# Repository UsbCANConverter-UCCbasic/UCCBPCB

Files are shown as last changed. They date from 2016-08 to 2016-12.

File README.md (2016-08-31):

# PCB for UsbCANConverterBasic
This is PCB for UsbCANConverter basic, designed in free software KiCad.
#License
UsbCANConverterBasic is free software: you can redistribute it and/or modify it under the terms of the GNU Lesser General Public License as published by the Free Software Foundation, either version 3 of the License, or (at your option) any later version. Project is distributed in the hope that it will be useful, but WITHOUT ANY WARRANTY; without even the implied warranty of MERCHANTABILITY or FITNESS FOR A PARTICULAR PURPOSE. See the GNU Lesser General Public License for more details.

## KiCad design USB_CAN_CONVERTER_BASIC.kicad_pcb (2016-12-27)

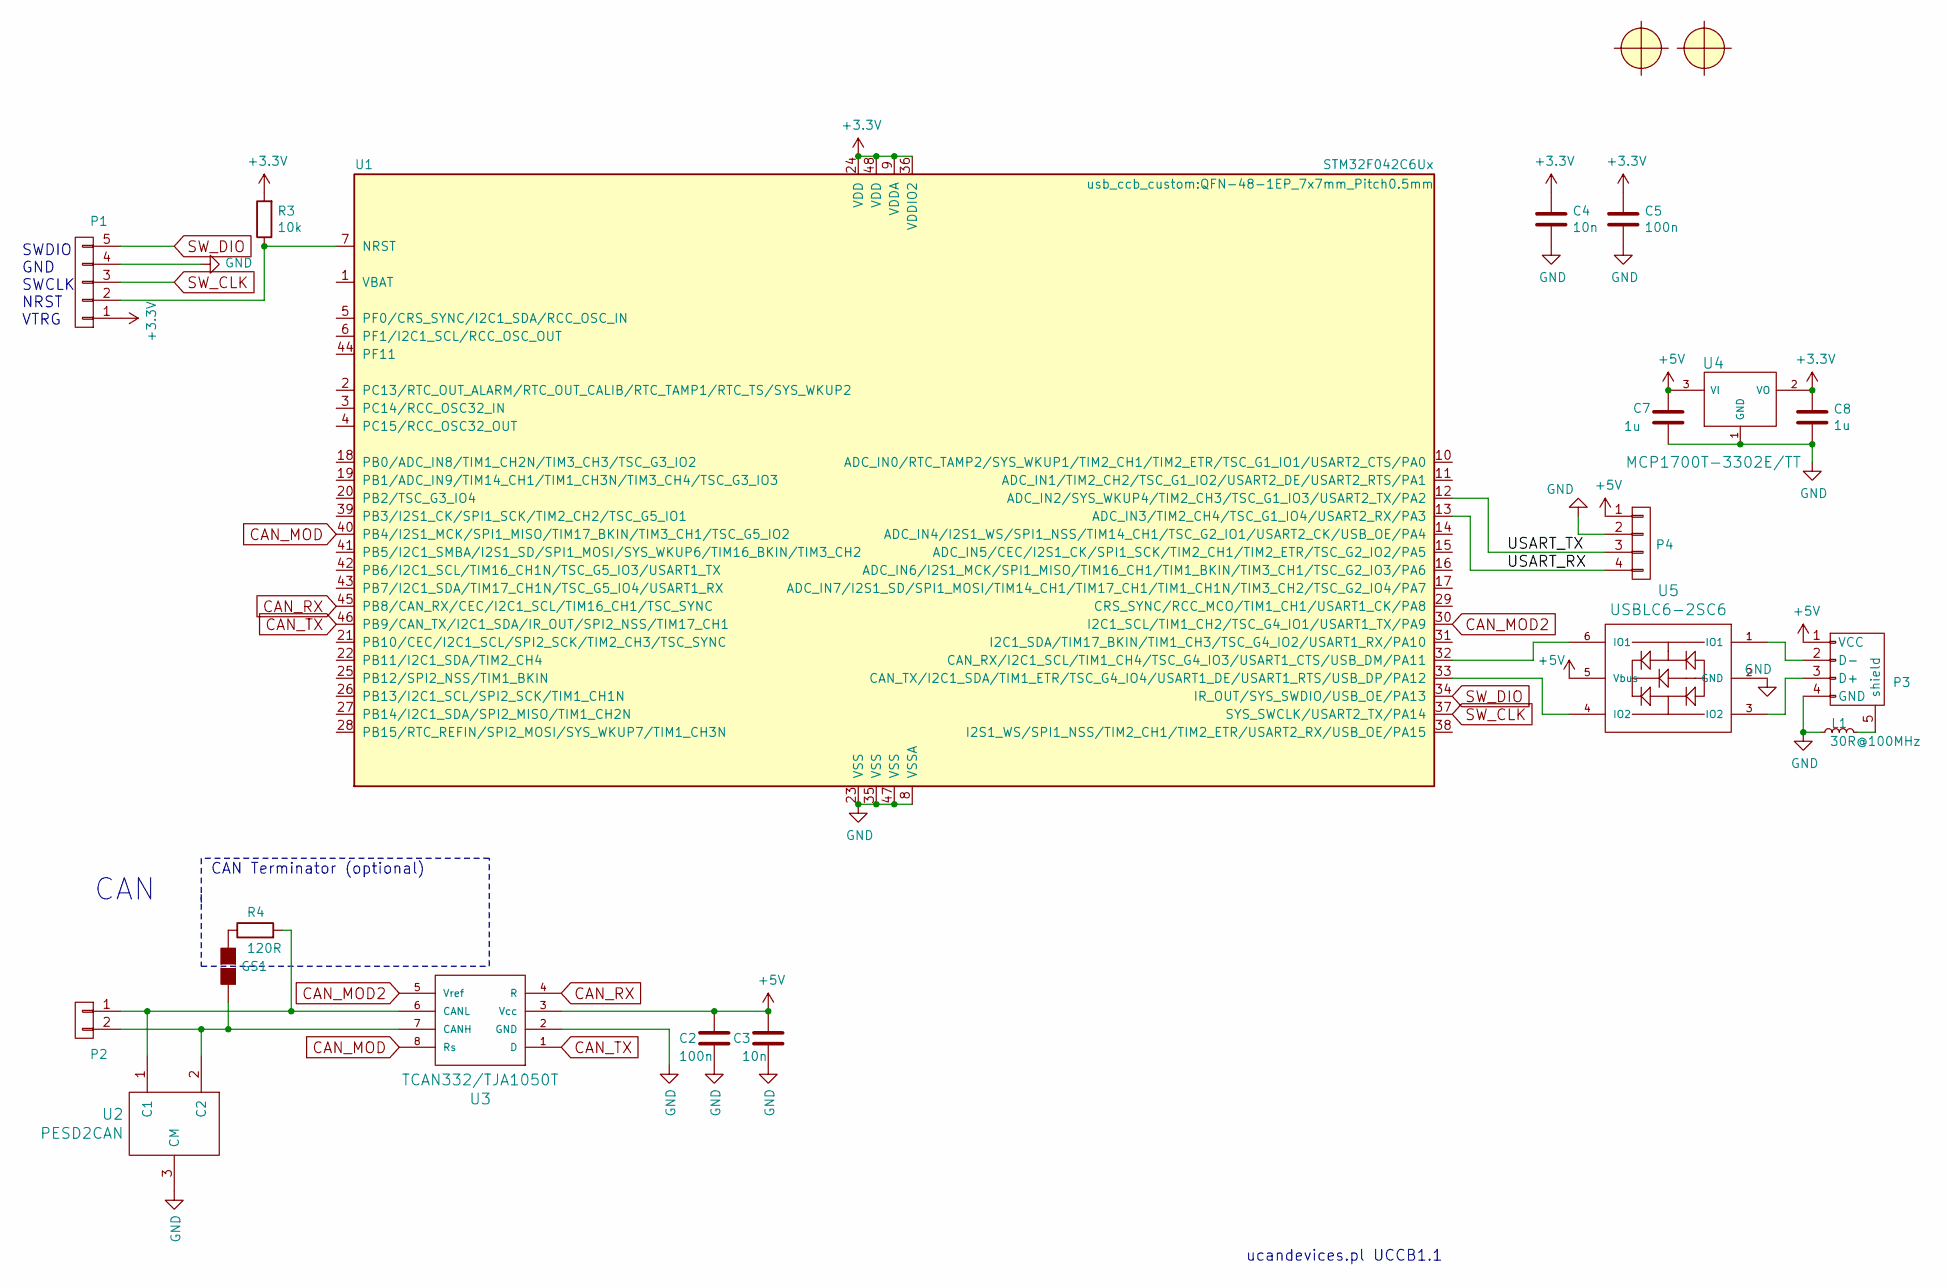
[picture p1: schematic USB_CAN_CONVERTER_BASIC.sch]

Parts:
C2, C5: 100n; C_0805; MFG Part Num C0805C104K3RAC
C3, C4: 10n; C_0805; MFG Part Num 08053C103KAT2A
C7, C8: 1u; C_0805; MFG Part Num 08053G105ZAT2A
F1: fiducial; Fiducial_1mm_Dia_2.54mm_Outer_CopperTop
F2: fiducial; Fiducial_1mm_Dia_2.54mm_Outer_CopperBottom
GS1: GS2
L1: 30R@100MHz; C_0805; MFG Part Num DL0805-0.82
P1: CONN_01X05; swd_smd_conn5
P2: CONN_01X02; AK300-2; MFG Part Num DG126-5.0-2P14
P3: USB_A; USB_A_DS1097R; MFG Part Num DS1097-BN0
P4: CONN_01X04; Pin_Header_Angled_1x04m
R3: 10k; R_0805; MFG Part Num CRCW080510K0FKEA
R4: 120R; R_0603; MFG Part Num SMD0805-120R
U1: STM32F042C6Ux; QFN-48-1EP_7x7mm_Pitch0.5mm; MFG Part Num STM32F042C6U6
U2: PESD2CAN; SOT-23; MFG Part Num PESD2CAN.215
U3: TCAN332/TJA1050T; SO; MFG Part Num TJA1050T/CM
U4: MCP1700T-3302E/TT; SOT-23; MFG Part Num MCP1700T-3302E/TT
U5: USBLC6-2SC6; SOT-23-6; MFG Part Num USBLC6-2SC6

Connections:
+3V3: C4.1, C5.1, C8.1, P1.1, R3.2, U1.9 (VDDA), U1.24 (VDD), U1.36 (VDDIO2), U1.48 (VDD), U4.2 (VO)
+5V: C2.1, C3.1, C7.1, P3.1 (VCC), P4.1, U3.3 (Vcc), U4.3 (VI), U5.5 (Vbus)
/USART_RX: P4.4, U1.13 (ADC_IN3/TIM2_CH4/TSC_G1_IO4/USART2_RX/P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)
/USART_TX: P4.3, U1.12 (ADC_IN2/SYS_WKUP4/TIM2_CH3/TSC_G1_IO3/U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)
CAN_MOD: U1.40 (PB4/I2S1_MCK/SPI1_MISO/TIM17_BKIN/TIM3_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), U3.8 (Rs)
CAN_MOD2: U1.30 (I2C1_SCL/TIM1_CH2/TSC_G4_IO1/USART1_TX/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), U3.5 (Vref)
CAN_RX: U1.45 (PB8/CAN_RX/CEC/I2C1_SCL/TIM16_CH1/TSC_S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), U3.4 (R)
CAN_TX: U1.46 (PB9/CAN_TX/I2C1_SDA/IR_OUT/SPI2_NSS/TIM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), U3.1 (D)
GND: C2.2, C3.2, C4.2, C5.2, C7.2, C8.2, L1.1, P1.4, P3.4 (GND), P4.2, U1.8 (VSSA), U1.23 (VSS), U1.35 (VSS), U1.47 (VSS), U1.49, U2.3 (CM), U3.2 (GND), U4.1 (GND), U5.2 (GND)
unnamed: GS1.1 (G1), R4.1
unnamed: GS1.2 (G2), P2.2, U2.2 (C2), U3.7 (CANH)
unnamed: L1.2, P3.5 (shield)
unnamed: P1.2, R3.1, U1.7 (NRST)
unnamed: P2.1, R4.2, U2.1 (C1), U3.6 (CANL)
unnamed: P3.2 (D-), U5.1 (IO1)
unnamed: P3.3 (D+), U5.3 (IO2)
unnamed: U1.32 (CAN_RX/I2C1_SCL/TIM1_CH4/TSC_G4_IO3/USA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), U5.6 (IO1)
unnamed: U1.33 (CAN_TX/I2C1_SDA/TIM1_ETR/TSC_G4_IO4/USA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), U5.4 (IO2)
SW_CLK: P1.3, U1.37 (SYS_SWCLK/USART2_TX/PA14)
SW_DIO: P1.5, U1.34 (IR_OUT/SYS_SWDIO/USB_OE/PA13)

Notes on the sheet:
SWDIO GND SWCLK NRST VTRG
CAN
CAN Terminator (optional)
ucandevices.pl UCCB1.1

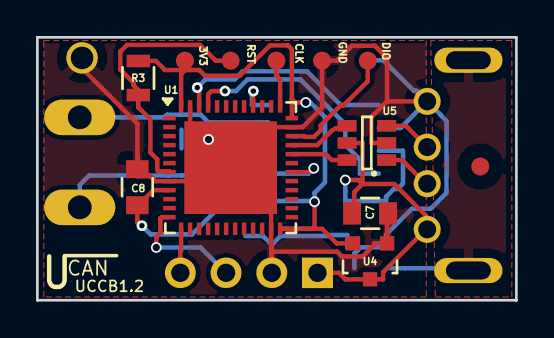
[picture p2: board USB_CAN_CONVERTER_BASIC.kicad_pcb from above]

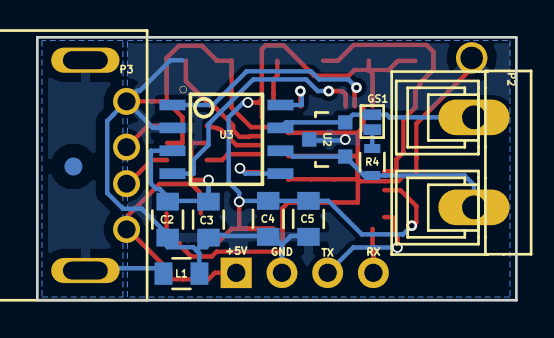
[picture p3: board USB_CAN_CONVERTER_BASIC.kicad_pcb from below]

Board: 2 copper layers, 26.6 x 14.6 mm, 21 parts (11 on the bottom side), 20 nets.

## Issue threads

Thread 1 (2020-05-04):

Modify board to add placeholder for smd dip switch and termination resistor

ksuszka, 2020-05-04:
Just an idea - there is a place for termination resistor already on board, however it would be nice to have ability to enable/disable it without soldering. It could be achieved by adding resistor with binary dip switch in series. It could be optional, as it shouldn't interfere with the rest of the board.

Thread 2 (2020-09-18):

Schema says TCAN332 or TJA1050, but only TJA1050 works

daniellandau, 2020-09-18:
TCAN332 requires 3.3V Vcc and refuses to send/receive anything when supplied with 5V as current UCCB design does.

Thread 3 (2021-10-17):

Suggestion: Configuration Jumpers

milesfrain, 2021-10-17:
For future HW revisions, it would be great to have easy configuration with 0.1" pitch jumpers on the following:
- `GS1` for termination (and / or the switch footprint suggestion in #1)
- Breaking `CAN_TX` and `CAN_RX` so the board can be re-purposed as a simple transceiver breakout for testing CAN on other micros (e.g. without using the included STM32 and USB).

To keep manufacturing simple and not add to the BOM, just the through-hole footprints could be added for users to populate themselves if they wish. In the case of the `CAN_TX` and `CAN_RX` interruption, we can score the trace to break the existing connection.

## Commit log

2016-07-04 USB and CAN connector fix
    [USB_CAN_CONVERTER_BASIC.kicad_pcb, USB_CAN_CONVERTER_BASIC.sch]
2016-07-05 UART1 switch, logo creation, CAN footprint update, botom layer replacement.
    UART1 switch, logo creation, CAN footprint update, botom layer
    replacement.
    [USB_CAN_CONVERTER_BASIC.dsn, USB_CAN_CONVERTER_BASIC.kicad_pcb, USB_CAN_CONVERTER_BASIC.sch]
2016-07-09 SWD connector update, logo generation, board otline update.
    [USB_CAN_CONVERTER_BASIC.kicad_pcb, USB_CAN_CONVERTER_BASIC.sch]
2016-07-09 CAN Jumpers addition
    [USB_CAN_CONVERTER_BASIC.kicad_pcb, USB_CAN_CONVERTER_BASIC.sch]
2016-07-11 Outline size reduction
    [USB_CAN_CONVERTER_BASIC.dsn, USB_CAN_CONVERTER_BASIC.kicad_pcb, USB_CAN_CONVERTER_BASIC.sch]
2016-07-11 USART change
    [USB_CAN_CONVERTER_BASIC.dsn, USB_CAN_CONVERTER_BASIC.kicad_pcb, USB_CAN_CONVERTER_BASIC.sch]
2016-07-12 Board rooting done.
    [USB_CAN_CONVERTER_BASIC.dsn, USB_CAN_CONVERTER_BASIC.kicad_pcb, USB_CAN_CONVERTER_BASIC.sch]
2016-07-12 Thermal pad update
    [USB_CAN_CONVERTER_BASIC.dsn, USB_CAN_CONVERTER_BASIC.kicad_pcb]
2016-07-12 BOM addition
    [bom.xlsx]
2016-07-13 Rooting and CANmod replace.
    [USB_CAN_CONVERTER_BASIC.dsn, USB_CAN_CONVERTER_BASIC.kicad_pcb, USB_CAN_CONVERTER_BASIC.sch]
2016-07-13 Gerber and drill generation
    [USB_CAN_CONVERTER_BASIC-B.CrtYd.gbr, USB_CAN_CONVERTER_BASIC-B.Cu.gbl, USB_CAN_CONVERTER_BASIC-B.Cu.gbr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]
2016-07-13 BOM update
    BOM update
    [bom.xlsx]
2016-08-13 Panel pcb addition and stencils.
    [USB_CAN_CONVERTER_BASIC.sch, bom.xlsx]
2016-10-04 Schematic name update
    Schematic name update
    [USB_CAN_CONVERTER_BASIC.sch]
2016-12-08 Fiducial Add
    Fiducial Add
    [USB_CAN_CONVERTER_BASIC.kicad_pcb, USB_CAN_CONVERTER_BASIC.sch]
2016-12-08 components description update
    components description update
    [USB_CAN_CONVERTER_BASIC.kicad_pcb, USB_CAN_CONVERTER_BASIC.sch]
2016-12-09 Update Outputs
    Update Outputs
    [USB_CAN_CONVERTER_BASIC-B.CrtYd.gbr, USB_CAN_CONVERTER_BASIC-B.Cu.gbl, USB_CAN_CONVERTER_BASIC-B.Fab.gbr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]
2016-12-27 Gerber update
    Gerber update
    [USB_CAN_CONVERTER_BASIC-B.CrtYd.gbr, USB_CAN_CONVERTER_BASIC-B.Cu.gbl, USB_CAN_CONVERTER_BASIC-B.Fab.gbr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]
2017-01-23 gerber updates
